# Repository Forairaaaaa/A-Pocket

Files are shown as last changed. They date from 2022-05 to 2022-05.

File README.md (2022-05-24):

# A-Pocket - 基于全志A133的掌上终端

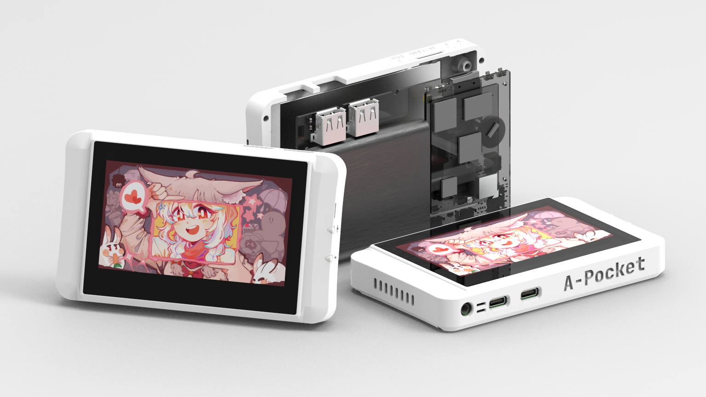
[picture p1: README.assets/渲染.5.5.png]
渲染.5.5


视频介绍：[【开源】 自 制 手 机 ：【一】PDA？_哔哩哔哩_bilibili](https://www.bilibili.com/video/BV11t4y1W7DJ#reply114174036736)

虽然是奔着DIY手机去的，不知咋的就做成PDA了（

由于屏幕特殊，性价比极低，不建议复刻除核心板外的其他东西。

### 硬件组成

- **核心板**：板载全志A133邮票孔模块、USB-OTG、USB-Debug、带MIC的3.5mm耳机接口、扬声器接口、电池接口、MPU6050、RTC等，单板即可满足正常工作。另外由板对板引出显示屏接口和USB接口供拓展。未引出A133提供的摄像头接口。
- **拓展板**：板载LCD背光电路、USB5V的DC-DC升压电路和USB-HUB电路等。
- **散热**：背壳贴石墨烯，由导热硅垫传热

### 软件组成

核心模组厂商提供了安卓10和Ubuntu的镜像，要适配屏幕只需要简单修改设备树的配置文件即可。

### 物件参考链接

- [HelperBoard A133核心板（安卓10、ub，全志A133，内置5G-WIFI）-淘宝网 (taobao.com)](https://item.taobao.com/item.htm?spm=a1z09.2.0.0.fae32e8dKwhqRd&id=646476965103&_u=o2bdtj0f16a5)
- [适用智力快车儿童视频学习机早教机锂电池3.7V大容量10000mah充电-tmall.com天猫](https://detail.tmall.com/item.htm?id=613087896696&spm=a1z09.2.0.0.fae32e8dKwhqRd&_u=o2bdtj0fb0d2)   955565
- [3.8寸IPS液晶显示模块 电容触摸屏1024*600 JD9168, LVDS接口-tmall.com天猫](https://detail.tmall.com/item.htm?id=652122490131&spm=a1z09.2.0.0.fae32e8dKwhqRd&_u=o2bdtj0f7da0)

### 缺点

屏幕性价比低，屏占比低，核心模组也比较贵

板对板连接导致厚度大，扬声器音质很烂

### 待改进

改用量产的手机MIPI屏幕，但需要学写驱动（泪目

主控想改用RK3399或RK3588，但价格~~

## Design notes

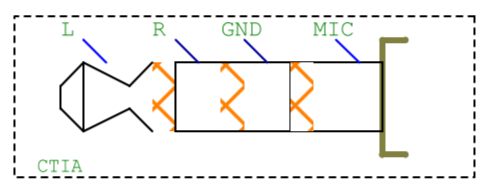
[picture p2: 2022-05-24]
Hardware/Kicad/A133CoreDK/uTools_1650608009190.png

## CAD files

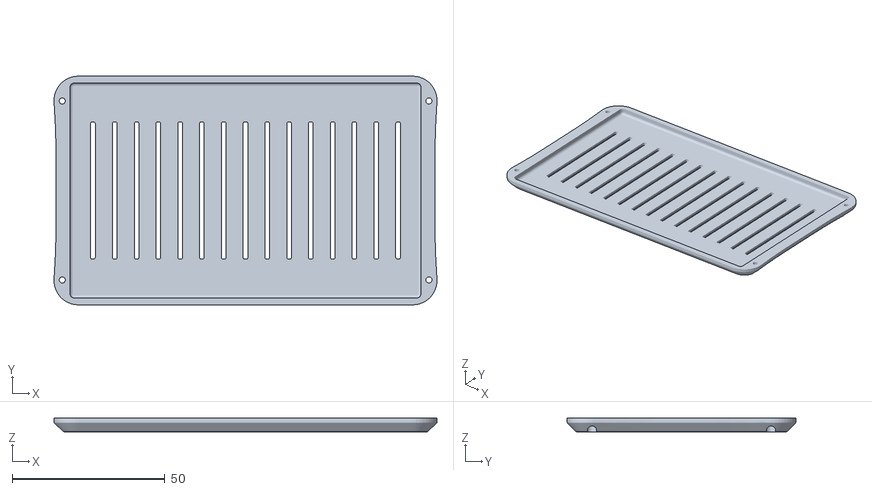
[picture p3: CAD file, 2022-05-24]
Models/打印/后盖.stl
125.6 x 75.0 x 4.44

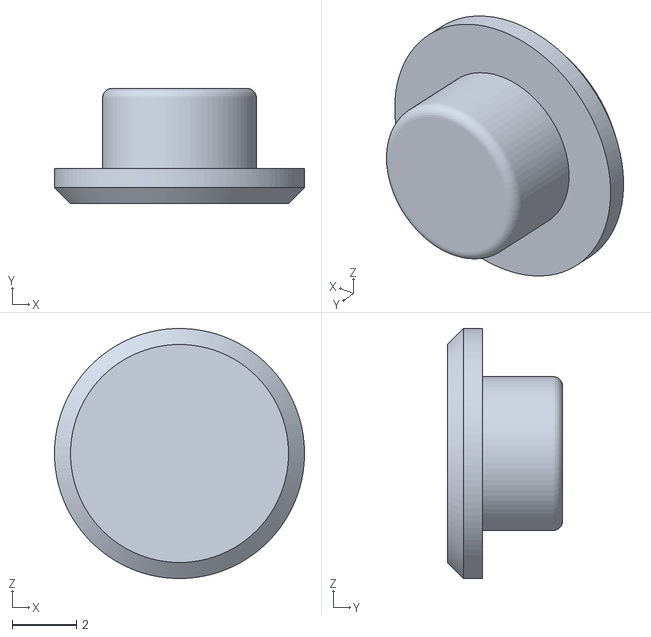
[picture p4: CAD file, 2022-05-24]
Models/打印/按键2x1.stl
7.80 x 3.60 x 7.80

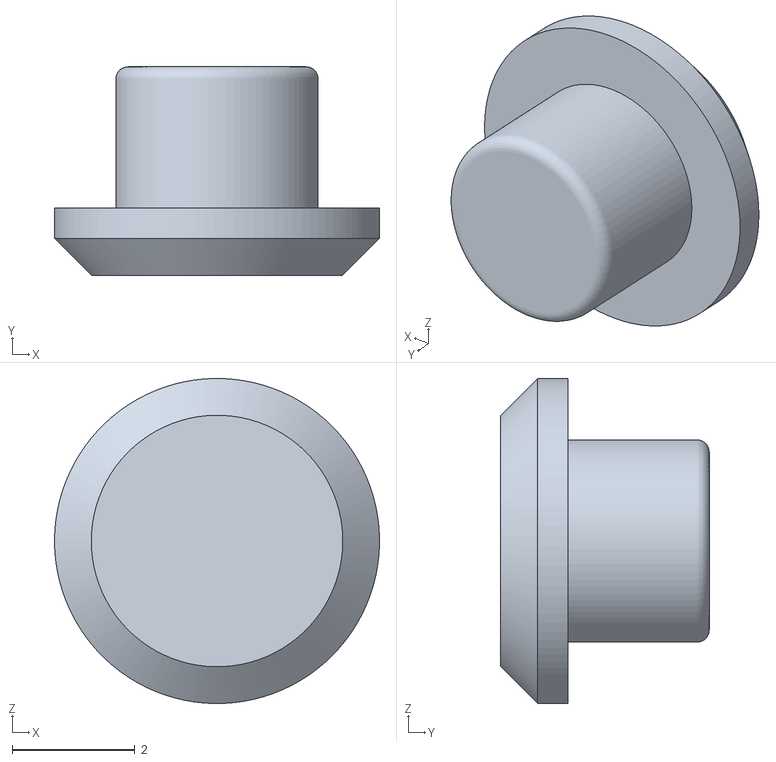
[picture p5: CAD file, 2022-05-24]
Models/打印/按键3x2.stl
5.30 x 3.40 x 5.30

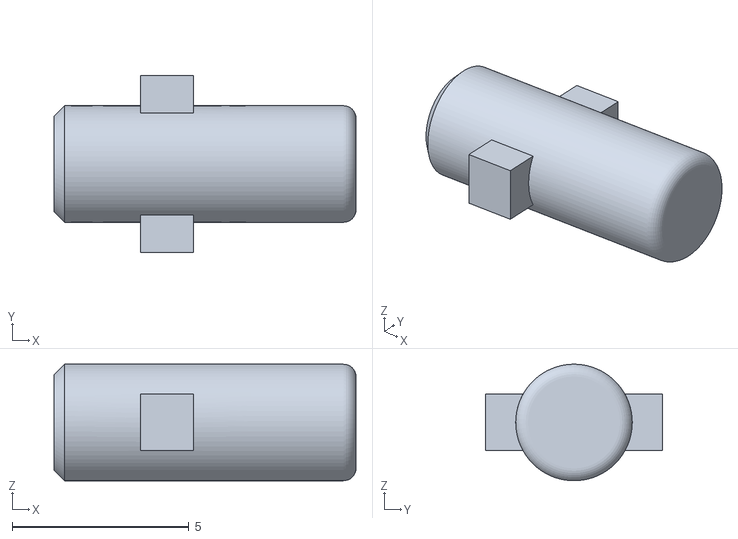
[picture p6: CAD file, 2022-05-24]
Models/打印/按键1x2.stl
8.55 x 5.00 x 3.30

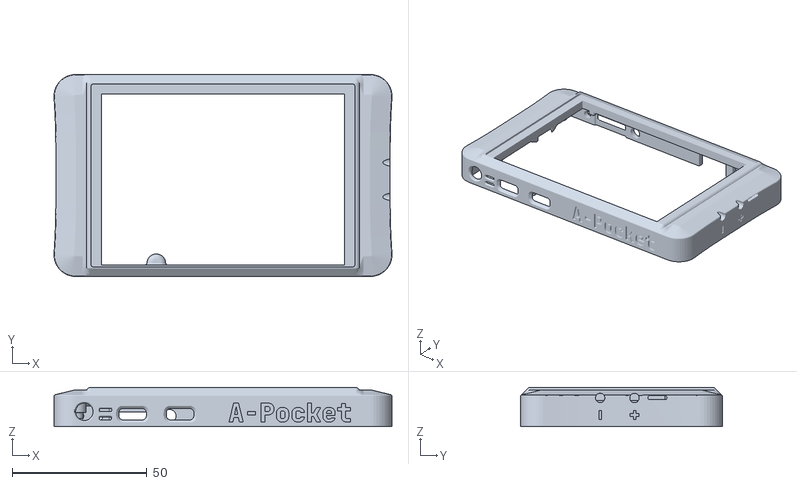
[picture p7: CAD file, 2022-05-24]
Models/打印/外壳.stl
125.6 x 75.0 x 14.6

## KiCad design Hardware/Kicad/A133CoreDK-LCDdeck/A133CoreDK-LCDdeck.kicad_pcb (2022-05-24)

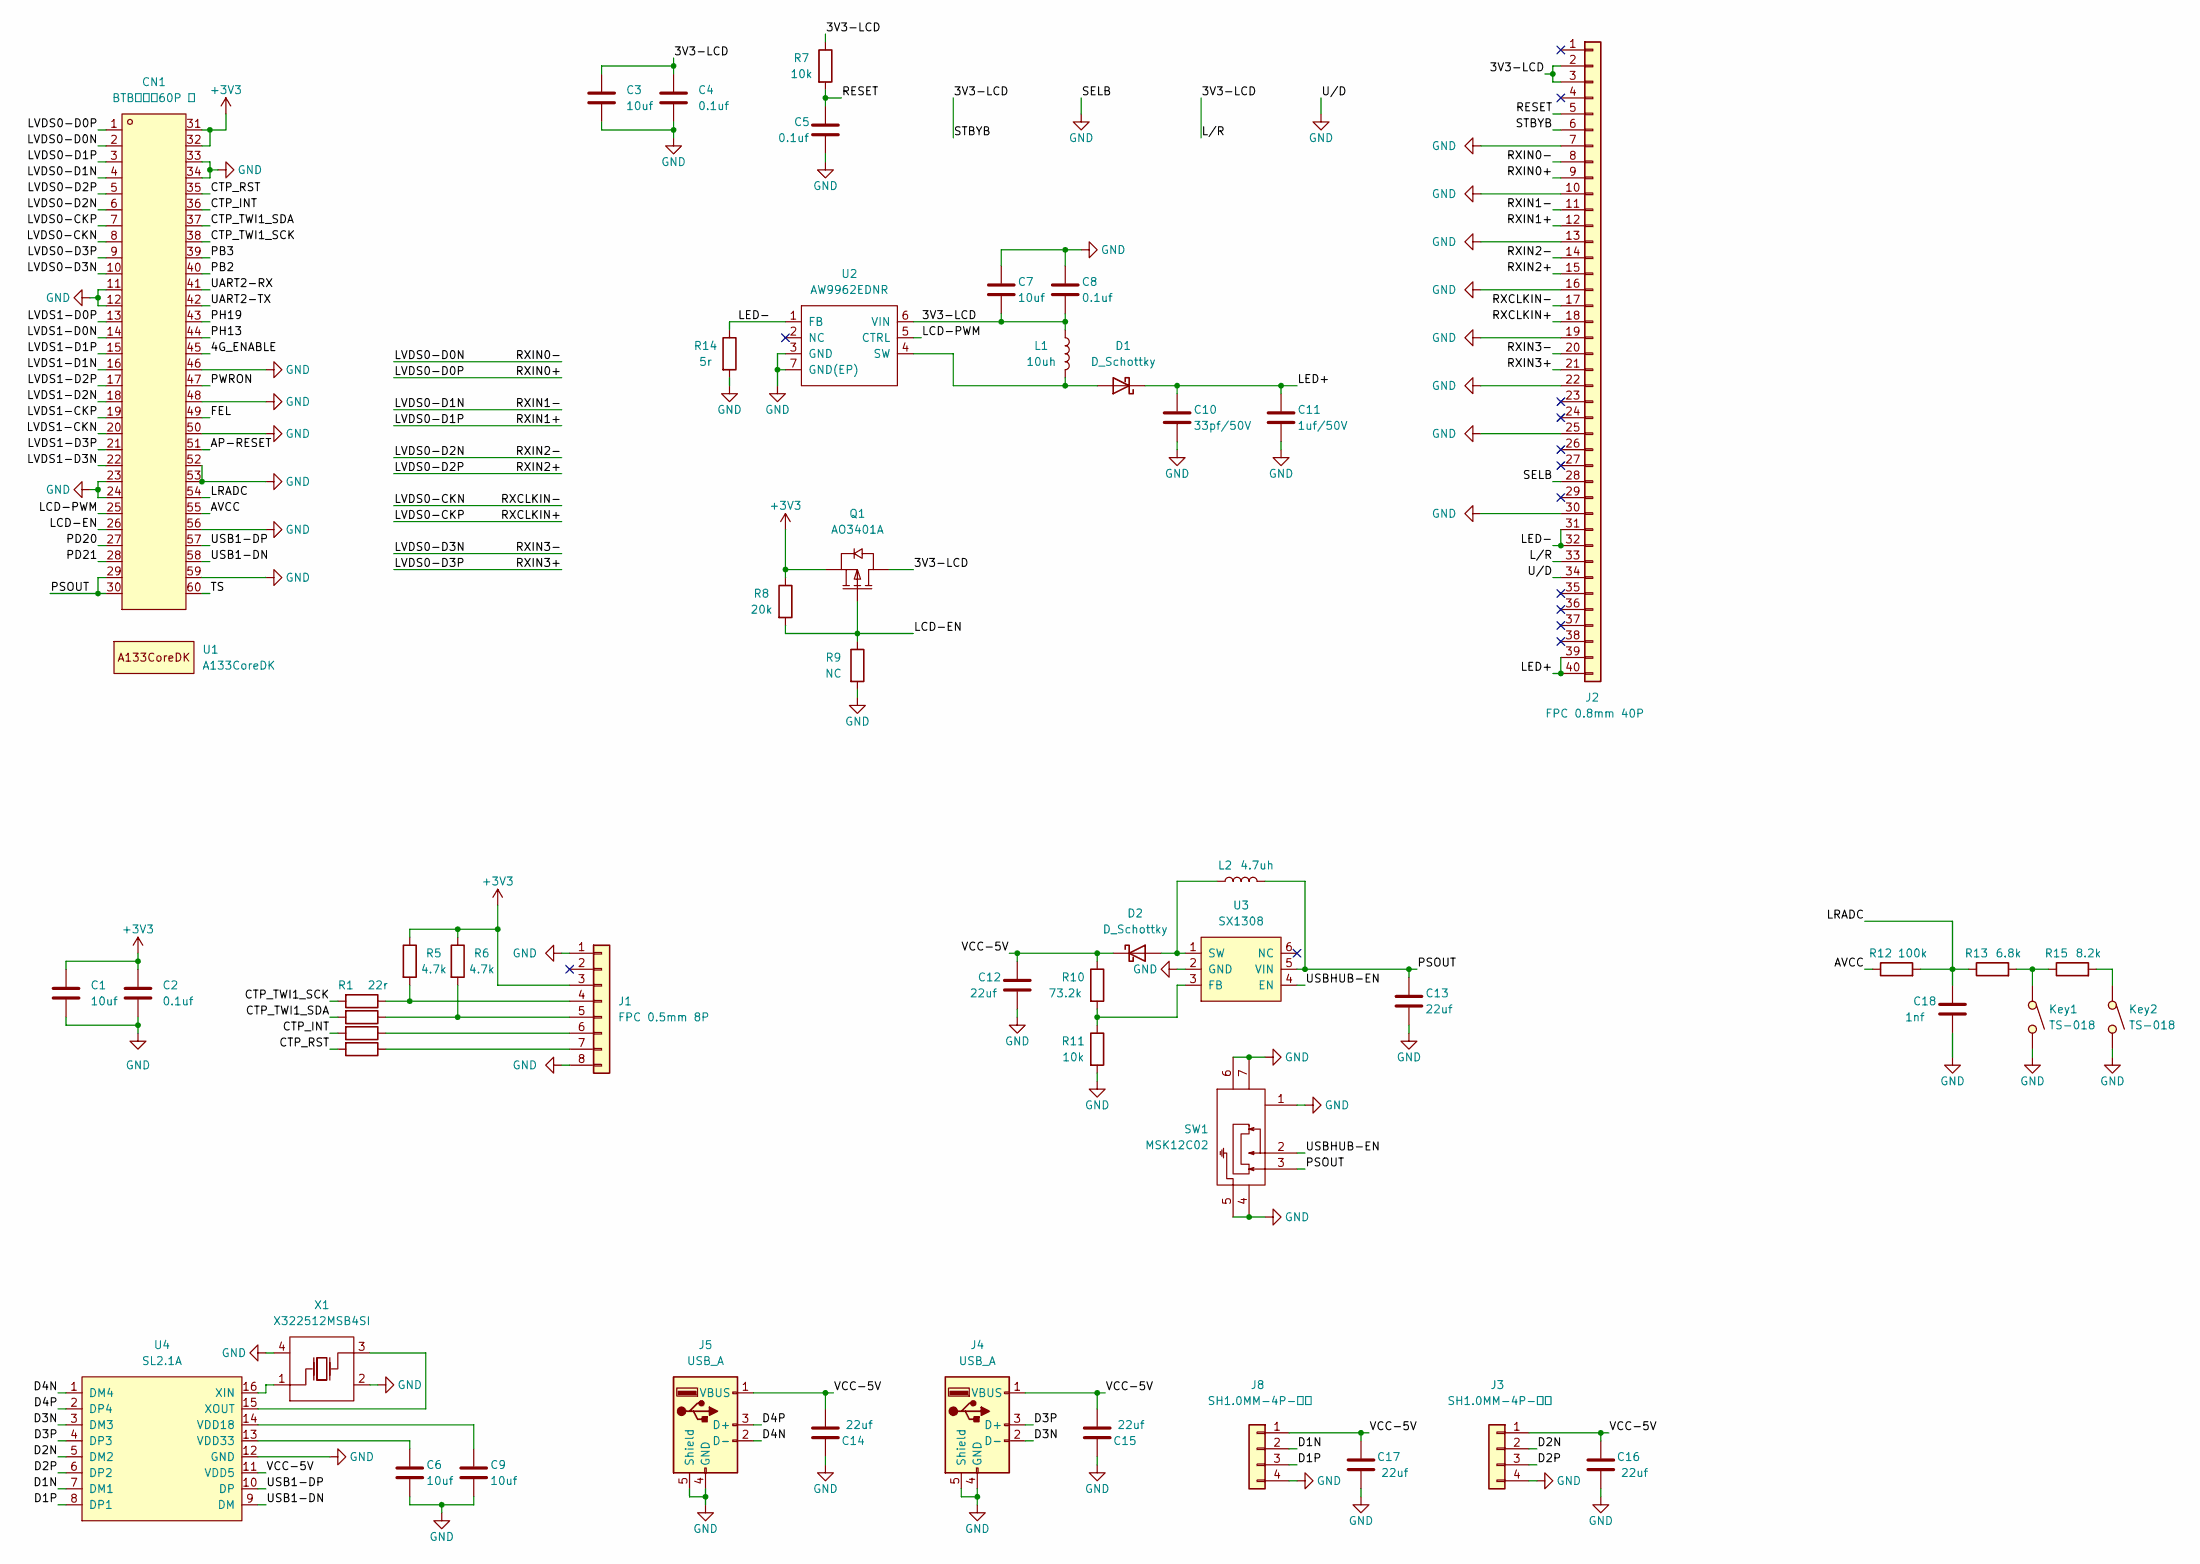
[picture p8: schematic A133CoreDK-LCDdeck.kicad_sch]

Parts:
C1, C3, C6, C7, C9: 10uf; C_0402_1005Metric
C2, C4, C5, C8: 0.1uf; C_0402_1005Metric
C10: 33pf/50V; C_0603_1608Metric
C11: 1uf/50V; C_0603_1608Metric
C12, C13, C14, C15, C16, C17: 22uf; C_0603_1608Metric
C18: 1nf; C_0402_1005Metric
CN1: BTB板对板60P 母
D1, D2: D_Schottky; D_SOD-123
J1: FPC 0.5mm 8P; TE_0-1734839-8_1x08-1MP_P0.5mm_Horizontal
J2: FPC 0.8mm 40P; TE_4-1734839-0_1x40-1MP_P0.5mm_Horizontal
J3, J8: SH1.0MM-4P-卧贴; SH1.0MM-卧贴-4P-CONN-SMD_1.0T-4P
J4, J5: USB_A; USB-A-SMD_FUS270-FSBW5K
Key1, Key2: TS-018; SW-SMD_TS24CA
L1: 10uh; CD32贴片电感-IND-SMD_L3.5-W3.0
L2: 4.7uh; CD32贴片电感-IND-SMD_L3.5-W3.0
Q1: AO3401A; SOT-23
R1, R2, R3, R4: 22r; R_0402_1005Metric
R5, R6: 4.7k; R_0402_1005Metric
R7, R11: 10k; R_0402_1005Metric
R8: 20k; R_0402_1005Metric
R9: NC; R_0402_1005Metric
R10: 73.2k; R_0402_1005Metric
R12: 100k; R_0402_1005Metric
R13: 6.8k; R_0402_1005Metric
R14: 5r; R_0402_1005Metric
R15: 8.2k; R_0402_1005Metric
SW1: MSK12C02; SW-TH_MSK12C02
U1: A133CoreDK
U2: AW9962EDNR; TDFN-6_L2.0-W2.0-P0.65-BL-EP
U3: SX1308; SOT-23-6
U4: SL2.1A; SOP-16_3.9x9.9mm_P1.27mm
X1: X322512MSB4SI; OSC-SMD_4P-L3.2-W2.5-BL

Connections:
+3V3: C1.1, C2.1, CN1.31, CN1.32, J1.3, Q1.2 (S), R5.1, R6.1, R8.1
/3V3-LCD: C3.1, C4.1, C7.2, C8.2, J2.2, J2.3, J2.6, J2.33, L1.1, Q1.3 (D), R7.1, U2.6 (VIN)
/4G_ENABLE: CN1.45
/AP-RESET: CN1.51
/AVCC: CN1.55, R12.1
/CTP_INT: CN1.36, R3.2
/CTP_RST: CN1.35, R4.2
/CTP_TWI1_SCK: CN1.38, R1.2
/CTP_TWI1_SDA: CN1.37, R2.2
/D1N: J8.2, U4.7 (DM1)
/D1P: J8.3, U4.8 (DP1)
/D2N: J3.2, U4.5 (DM2)
/D2P: J3.3, U4.6 (DP2)
/D3N: J4.2 (D-), U4.3 (DM3)
/D3P: J4.3 (D+), U4.4 (DP3)
/D4N: J5.2 (D-), U4.1 (DM4)
/D4P: J5.3 (D+), U4.2 (DP4)
/FEL: CN1.49
/LCD-EN: CN1.26, Q1.1 (G), R8.2, R9.1
/LCD-PWM: CN1.25, U2.5 (CTRL)
/LED+: C10.1, C11.1, D1.1 (K), J2.39, J2.40
/LED-: J2.31, J2.32, R14.1, U2.1 (FB)
/LRADC: C18.1, CN1.54, R12.2, R13.1
/LVDS0-CKN: CN1.8, J2.17
/LVDS0-CKP: CN1.7, J2.18
/LVDS0-D0N: CN1.2, J2.8
/LVDS0-D0P: CN1.1, J2.9
/LVDS0-D1N: CN1.4, J2.11
/LVDS0-D1P: CN1.3, J2.12
/LVDS0-D2N: CN1.6, J2.14
/LVDS0-D2P: CN1.5, J2.15
/LVDS0-D3N: CN1.10, J2.20
/LVDS0-D3P: CN1.9, J2.21
/LVDS1-CKN: CN1.20
/LVDS1-CKP: CN1.19
/LVDS1-D0N: CN1.14
/LVDS1-D0P: CN1.13
/LVDS1-D1N: CN1.16
/LVDS1-D1P: CN1.15
/LVDS1-D2N: CN1.18
/LVDS1-D2P: CN1.17
/LVDS1-D3N: CN1.22
/LVDS1-D3P: CN1.21
/PB2: CN1.40
/PB3: CN1.39
/PD20: CN1.27
/PD21: CN1.28
/PH13: CN1.44
/PH19: CN1.43
/PSOUT: C13.1, CN1.29, CN1.30, L2.2, SW1.3, U3.5 (VIN)
/PWRON: CN1.47
/RESET: C5.1, J2.5, R7.2
/TS: CN1.60
/UART2-RX: CN1.41
/UART2-TX: CN1.42
/USB1-DN: CN1.58, U4.9 (DM)
/USB1-DP: CN1.57, U4.10 (DP)
/USBHUB-EN: SW1.2, U3.4 (EN)
/VCC-5V: C12.1, C14.2, C15.2, C16.1, C17.1, D2.1 (K), J3.1, J4.1 (VBUS), J5.1 (VBUS), J8.1, R10.1, U4.11 (VDD5)
GND: C1.2, C2.2, C3.2, C4.2, C5.2, C6.2, C7.1, C8.1, C9.2, C10.2, C11.2, C12.2, C13.2, C14.1, C15.1, C16.2, C17.2, C18.2, CN1.11, CN1.12, CN1.23, CN1.24, CN1.33, CN1.34, CN1.46, CN1.48, CN1.50, CN1.52, CN1.53, CN1.56, CN1.59, J1.1, J1.8, J2.7, J2.10, J2.13, J2.16, J2.19, J2.22, J2.25, J2.28, J2.30, J2.34, J3.4, J4.4 (GND), J4.5 (Shield), J5.4 (GND), J5.5 (Shield), J8.4, Key1.2, Key2.2, R9.2, R11.2, R14.2, SW1.1, SW1.4, SW1.5, SW1.6, SW1.7, U2.3 (GND), U2.7 (GND(EP)), U3.2 (GND), U4.12 (GND), X1.2 (GND), X1.4 (GND)
unnamed: C6.1, U4.13 (VDD33)
unnamed: C9.1, U4.14 (VDD18)
unnamed: D1.2 (A), L1.2, U2.4 (SW)
unnamed: D2.2 (A), L2.1, U3.1 (SW)
unnamed: J1.4, R1.1, R5.2
unnamed: J1.5, R2.1, R6.2
unnamed: J1.6, R3.1
unnamed: J1.7, R4.1
unnamed: Key1.1, R13.2, R15.1
unnamed: Key2.1, R15.2
unnamed: R10.2, R11.1, U3.3 (FB)
unnamed: U4.15 (XOUT), X1.3 (OSC2)
unnamed: U4.16 (XIN), X1.1 (OSC1)

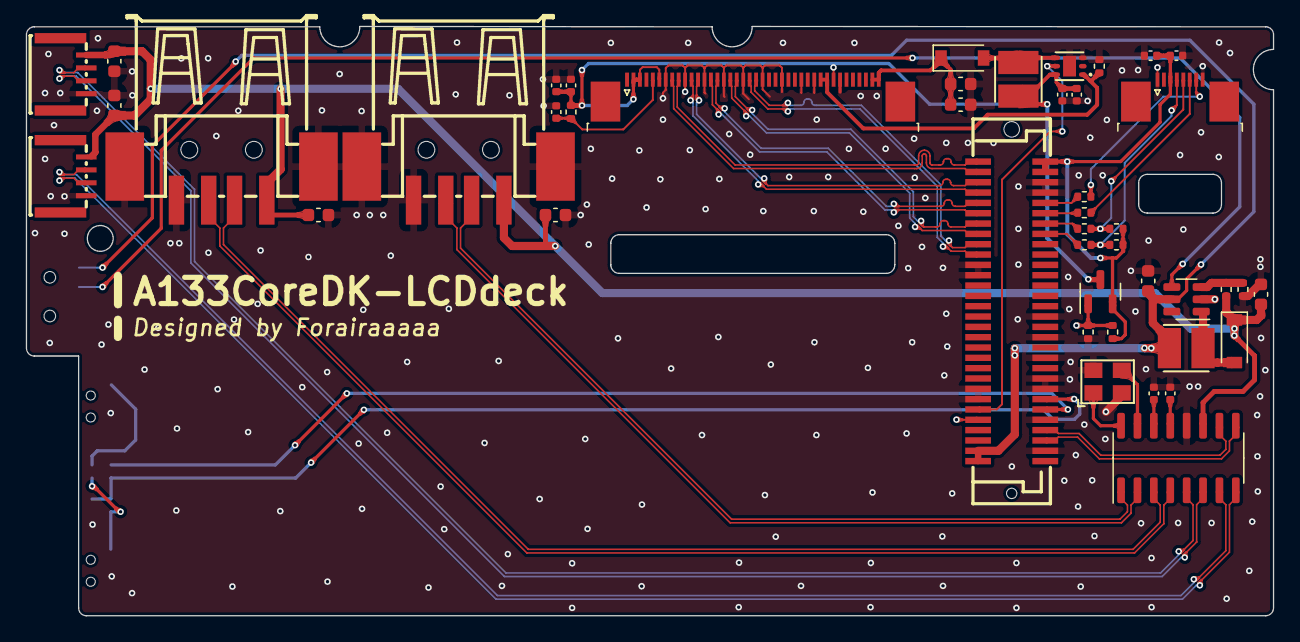
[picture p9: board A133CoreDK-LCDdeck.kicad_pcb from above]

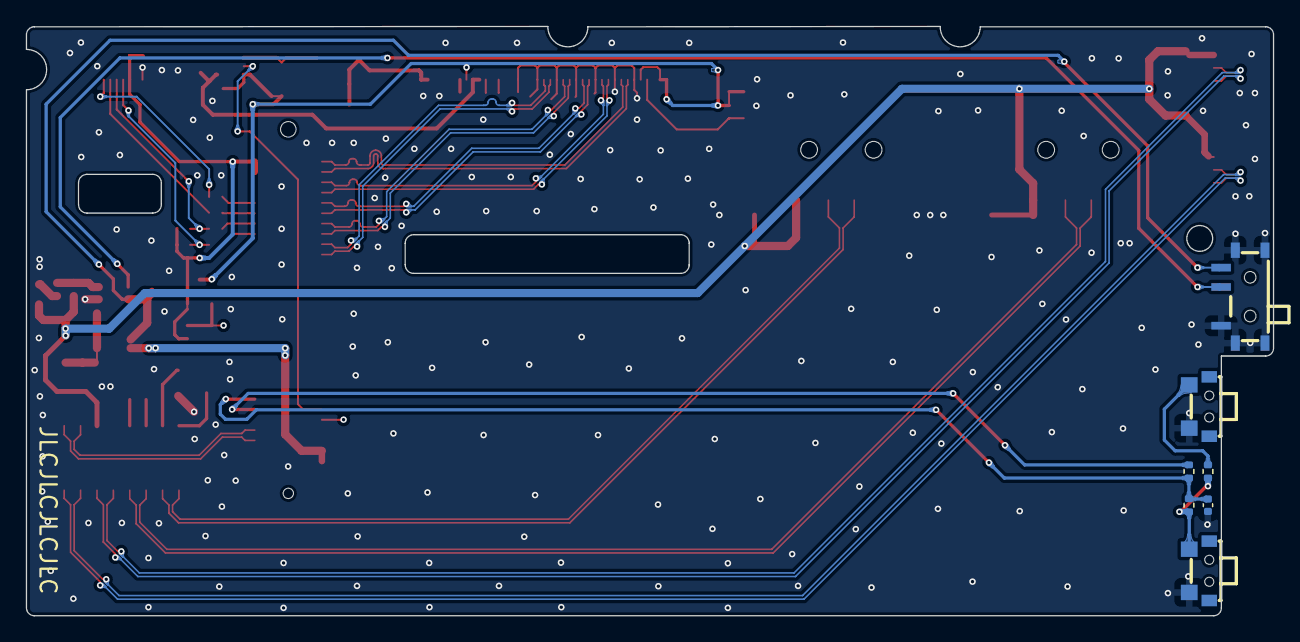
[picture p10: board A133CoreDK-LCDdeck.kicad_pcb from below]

Board: 4 copper layers, 96.6 x 45.6 mm, 53 parts (7 on the bottom side), 50 nets.
